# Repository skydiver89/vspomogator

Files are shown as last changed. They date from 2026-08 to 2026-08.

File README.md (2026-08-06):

**Languages**  
* [English](README.md)
* [Русский](README-RU.md)
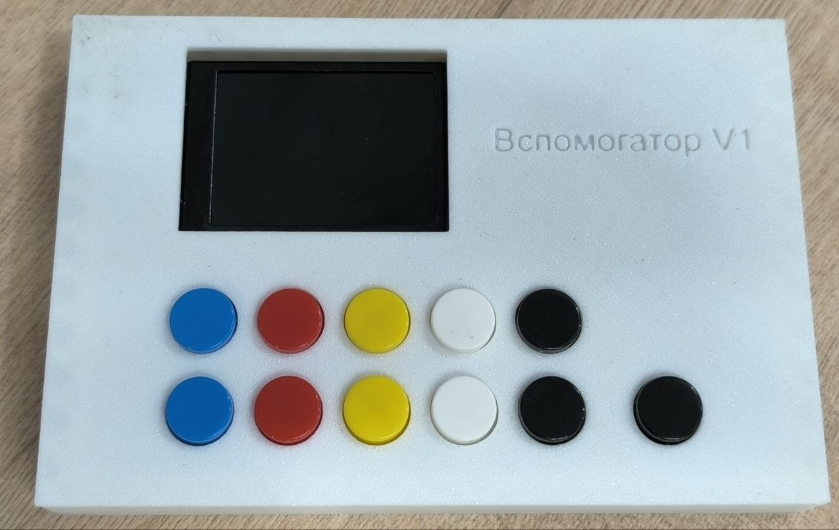
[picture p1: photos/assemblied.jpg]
Vspomogator V1

## Description  
**Vspomogator** — this is programmable macrokeyboard with display, which connecting to PC by USB (via virtual COM-port). Device allows to run commands, emulate text typing or pressing key combinations. Buttons grouped in layouts. Display shows current layout or sytsem info (CPU temperature and load, RAM usage, network activity, battery status). 11 buttons totally. Buttons are enumerated from 1 to 11 from left to right, from top to bottom.  
## Possibilities
- **2 modes**:
  - **Layouts mode**: shows button names according to configuration file.  
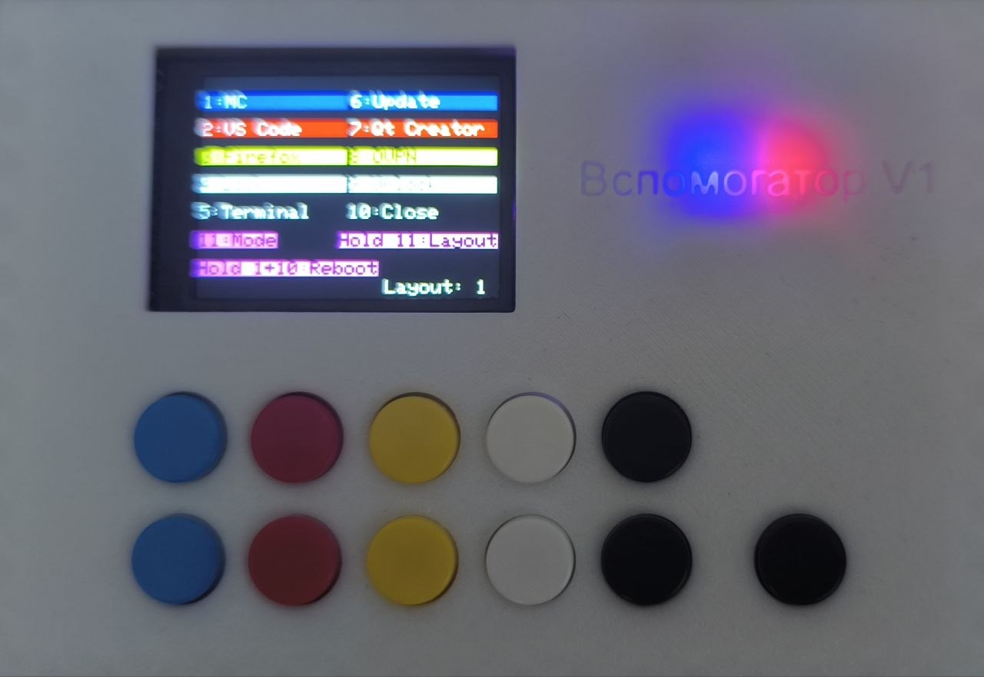
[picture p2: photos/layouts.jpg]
Layouts
  
  - **System info mode**: shows CPU load (common and by cores), RAM usage, CPU temperature, network activity (Tx/Rx) and battery status.  
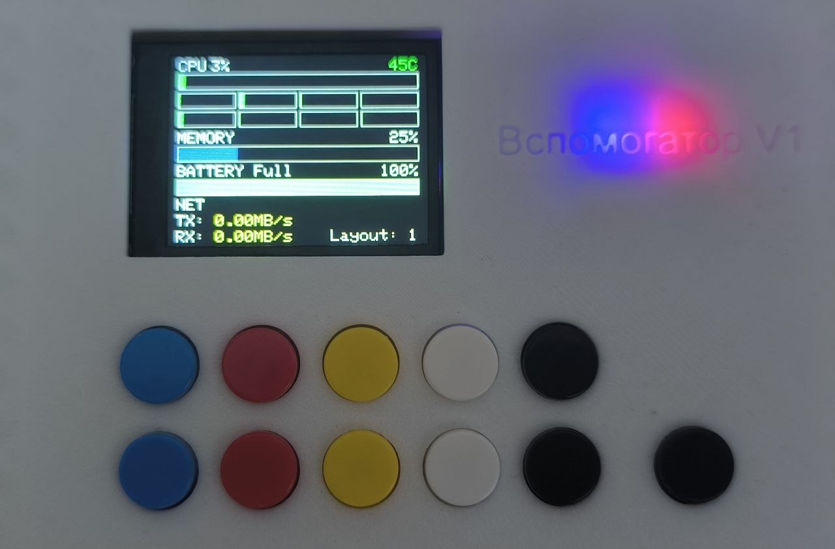
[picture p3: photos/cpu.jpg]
System info
  
- **Mode changing** is performing by pressing button 11.  
- **Layout changing** is performing by long pressing button 11.  
- **Reboot** is performing by long pressing buttons 1+10.  
## Materials used  
- **ESP32** DevKitV1 with CP2102 chip - some China clone. https://ozon.ru/t/zLtqDSa
- **TFT LCD display 240x320** on ST7789 chip. https://ozon.ru/t/WcsNvLD
- **11 tactile buttons** https://ozon.ru/t/3Qol6bx
- **breadboard** 12x8 https://ozon.ru/t/QWNoiOu
- **wires**
- **pin headers**. The display comes with a pin header for only one side. https://ozon.ru/t/dwWQEG1
- **device housing** is 3d-printed. Models are in *3d models* directory  
## Pinout  
### Display  
| ESP32 | ST7789 |
|---|---|
| 3V3 | VDD,BL |
| GND | GND |
| D2 | DC |
| D4 | RES |
| D5 | CS |
| D18 | SCL |
| D23 | SDA |
### Buttons  
One pin of each button is connected to the ESP32 GND. The second pins:
| ESP32 | Button |
|---|---|
| D13 | 1 |
| D14 | 2 |
| D16(RX2)| 3 |
| D17(TX2)| 4 |
| D19 | 5 |
| D21 | 6 |
| D22 | 7 |
| D25 | 8 |
| D26 | 9 |
| D27 | 10 |
| D33 | 11 |
## Element placing  
If you want to print the same housing, you need to place elements on breadboard exactly like in the photo:  
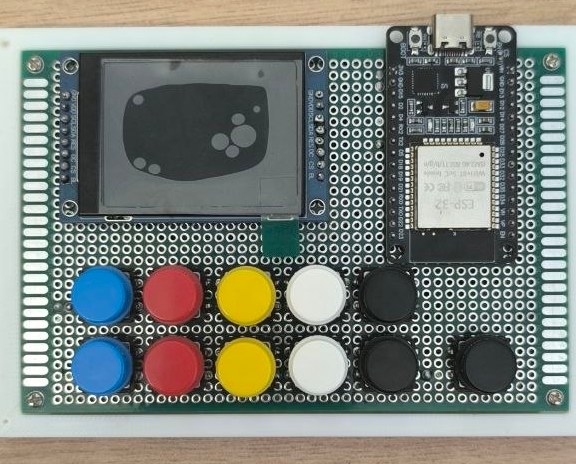
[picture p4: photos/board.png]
board
  
## Software  
### ESP32 firmware  
- In Arduino IDE choose board **ESP32 Dev Module**.
- Install libraries **TFT_eSPI**, **EncButton**, **ArduinoJson**.
- In library **TFT_eSPI** in file *UserSetup.h* (in my linux it`s location is *~/Arduino/libraries/TFT_eSPI/User_Setup.h*) change defines, as in file *User_Setup.h* in this repository. Or just replace the file.
- flash the ESP32.
### Service  
#### Requirements  
Out of the box it will work only in linux. For Windows it is should be modificated.  
#### Installation  
There is builded binary in relises for linux x86_64 and deb-package.  
There is also a systemd unit-file *service/buildscripts/vspomogator.service*. When the deb-package is installed, the systemd service will be installed and activated automatically, and the configuration file will be located at */etc/vspomogator/vspomogator.yml*.  
#### Building from source  
The Go compiler must be installed. Run the following in the directory *service*:

```
make
```

To build a deb package, [fpm](https://github.com/jordansissel/fpm) must be installed. Run the following in the directory *service*:

```
make deb
```

Binary and deb-package will appear in *build* directory.  
#### CLI arguments  

```
Usage: vspomogator [-c config] [-h] [-v]
  -c string
    	Path to config (default "vspomogator.yml")
  -h	Show this help
  -v	Show version
```

#### Configuration file  

```
port: /dev/ttyUSB0                     # The port to which the ESP32 is connected. It can be found in /dev/. It is usually /dev/ttyUSB0
layouts:
  - buttons:                           # first layout
    - label: MC                        # label on display
      type: command                    # action type (command - command, keytype - emulate keyaboard typing, keyseq - key combination. command is default)
      command:
        com: terminator                # Command to launch
        args: [-e, mc]                 # Arguments of command
    - label: Close
      type: keyseq                     # key combination
      command:
        com: "f4"                      # main key
        args: ["alt"]                  # modificators
    - label: Hello
      type: keytype                    # keyboard typing
      command:
        com: Hello, world!             # text to type
        hitenter: true                 # press enter after typing
  - buttons:                           # second layout
    ...
```

Modificators and keys for combinations look [here](https://github.com/go-vgo/robotgo/blob/master/docs/keys.md)

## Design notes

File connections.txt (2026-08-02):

ESP32	|	ST7789
----------------------
3V3	|	VDD,BL
GND	|	GND
D2	|	DC
D4	|	RES
D5	|	CS
D18	|	SCL
D23	|	SDA

1 pin of every button to GND, another one to:
ESP32	|	Buttons
-----------------------
D13	|	1
D14	|	2
D16(RX2)|	3
D17(TX2)|	4
D19	|	5
D21	|	6
D22	|	7
D25	|	8
D26	|	9
D27	|	10
D33	|	11

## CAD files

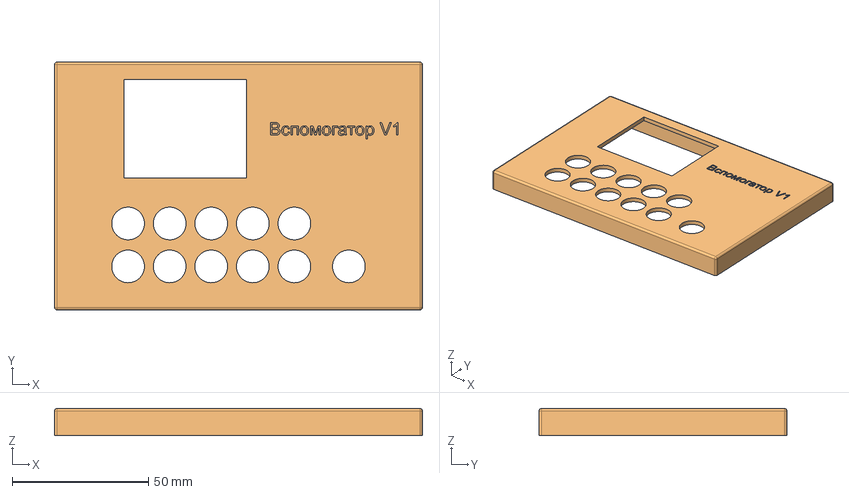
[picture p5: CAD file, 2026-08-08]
3d models/espboard_top.FCStd
135.0 x 91.0 x 10.0 mm
ShapeString

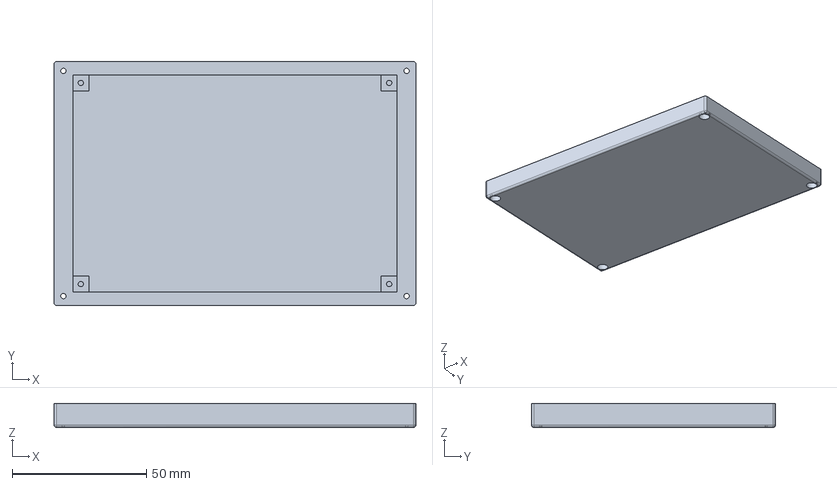
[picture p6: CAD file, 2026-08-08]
3d models/espboard_bottom.FCStd
135.0 x 91.0 x 9.00 mm

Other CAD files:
3d models/espboard_bottom.stl
3d models/espboard_top.stl

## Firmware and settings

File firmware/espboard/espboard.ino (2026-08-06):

#include <TFT_eSPI.h>
#include <SPI.h>
#include <EncButton.h>
#include <ArduinoJson.h>

#define INITREQ "begincmdinitendcmd"
#define INITOK "begincmdinitokendcmd"
#define STATREQ "begincmdstatendcmd"
#define INITINTERVAL 1000
#define STATINTERVAL 1000
#define RX_LINE_MAX 2048

bool initialized = false;
unsigned long lastInitSent = 0;
unsigned long lastStatSent = 0;
bool STATMODE = false;
bool statDrawn = false;
int curLayout = 0;
int layoutNum = 0;
JsonDocument conf;
String rxLine;

const int numBtns = 11;
Button btns[] = {Button(13), Button(14), Button(16), Button(17), Button(19),
                 Button(21), Button(22), Button(25), Button(26), Button(27), Button(33)};
VirtButton resetButton;

TFT_eSPI tft = TFT_eSPI();

void setup() {
  Serial.begin(115200);
  delay(100);
  tft.init();
  tft.setRotation(3);
  tft.fillScreen(TFT_BLACK);
  tft.setTextColor(TFT_WHITE, TFT_BLACK);
  tft.setTextSize(3);
  tft.drawString("Initializing...", 25, 110);
  tft.setTextSize(2);
  rxLine.reserve(256);
}

// Non-blocking: never deserializeJson(Serial) — it blocks loop()/buttons.
bool pollSerialLine(String &line) {
  while (Serial.available() > 0) {
    char c = (char)Serial.read();
    if (c == '\n' || c == '\r') {
      if (rxLine.length() == 0)
        continue;
      line = rxLine;
      rxLine = "";
      return true;
    }
    rxLine += c;
    if (rxLine.length() > RX_LINE_MAX)
      rxLine = "";
  }
  return false;
}

void drawLayout() {
  JsonArray root = conf.as<JsonArray>();
  JsonObject layout = root[curLayout].as<JsonObject>();
  JsonArray buttons = layout["Buttons"].as<JsonArray>();
  int x = 0;
  int y = 20;
  for (int i = 0; i < 10; i++) {
    String label = "";
    if (i < buttons.size()) {
      JsonObject btn = buttons[i].as<JsonObject>();
      label = String(btn["Label"]);
    }

    while (label.length() < 11)
      label += " ";
    if (i >= 5)
      x = 160;
    if (i == 0 || i == 5)
      tft.setTextColor(TFT_WHITE, TFT_BLUE);
    if (i == 1 || i == 6)
      tft.setTextColor(TFT_WHITE, TFT_RED);
    if (i == 2 || i == 7)
      tft.setTextColor(TFT_BLACK, TFT_YELLOW);
    if (i == 3 || i == 8)
      tft.setTextColor(TFT_BLACK, TFT_WHITE);
    if (i == 4 || i == 9)
      tft.setTextColor(TFT_WHITE, TFT_BLACK);
    tft.drawString(String(i + 1) + ":" + label, x, y);
    y += 30;
    if (i == 4)
      y = 20;
  }
  tft.setTextColor(TFT_BLACK, TFT_MAGENTA);
  tft.drawString("11:Mode", 0, 170);
  tft.drawString("Hold 11:Layout", 150, 170);
  tft.drawString("Hold 1+10:Reboot", 0, 200);
  tft.setTextColor(TFT_WHITE, TFT_BLACK);
  tft.drawString("Layout: " + String(curLayout + 1), 200, 220);
}

void requestInit() {
  unsigned long now = millis();
  if (now - lastInitSent < INITINTERVAL)
    return;
  lastInitSent = now;
  Serial.print(INITREQ);
}

void requestStat() {
  unsigned long now = millis();
  if (now - lastStatSent < STATINTERVAL)
    return;
  lastStatSent = now;
  Serial.print(STATREQ);
}

void handleConfig(JsonVariant data) {
  if (!data.is<JsonArray>())
    return;
  JsonArray root = data.as<JsonArray>();
  if (root.size() == 0)
    return;

  conf.clear();
  conf.set(data);
  layoutNum = root.size();
  if (curLayout >= layoutNum)
    curLayout = 0;

  bool wasInit = initialized;
  initialized = true;
  tft.fillScreen(TFT_BLACK);
  tft.setTextSize(2);
  drawLayout();
  if (!wasInit)
    Serial.print(INITOK);
}

void drawBar(int x, int y, int width, int height, int percentage, uint16_t color) {
  if (percentage < 0) percentage = 0;
  if (percentage > 100) percentage = 100;
  
  if(!statDrawn)
    tft.drawRect(x, y, width, height, TFT_WHITE);

  if (percentage > 0) {
    int fillWidth = (width - 2) * percentage / 100;
    tft.fillRect(x + 1, y + 1, fillWidth, height - 2, color);
    tft.fillRect(x + 1 + fillWidth, y + 1, width - 2 - fillWidth, height - 2, TFT_BLACK);
  }
}

uint16_t getLoadColor(int percentage) {
  if (percentage < 50) return TFT_GREEN;
  if (percentage < 75) return TFT_YELLOW;
  return TFT_RED;
}

void drawStatBar(int x, int y, int width, int height, const char* label, int percentage, uint16_t color, int textSize) {
  tft.setTextColor(TFT_WHITE, TFT_BLACK);
  tft.setTextSize(textSize);
  tft.drawString(label, x, y);
  
  String value = String(percentage) + "%";
  int valueX = x + width - tft.textWidth(value);
  tft.setTextColor(TFT_WHITE, TFT_BLACK);
  tft.drawString(value, valueX, y);
  
  drawBar(x, y + textSize * 8 + 2, width, height, percentage, color);
}

void handleStat(JsonVariant data) {
  if (!data.is<JsonObject>()) {
    return;
  }
  
  JsonObject stat = data.as<JsonObject>();
  
  int cores = stat["cores"];
  JsonArray percs = stat["percs"].as<JsonArray>();
  int mem = stat["mem"];
  int cputemp = stat["cputemp"];
  
  const char* nettx = stat["nettx"];
  const char* netrx = stat["netrx"];
  int bat = stat["bat"] | 0;
  const char* batstat = stat["batstat"];

  int totalLoad = 0;
  int coreCount = percs.size();
  
  int startY = 5;
  int barHeight = 20;
  int barStartX = 10;
  int barWidth = 300;
  
  int totalPerc = 0;
  for (int i = 0; i < coreCount; i++) {
    totalPerc += percs[i] | 0;
  }
  int avgLoad = coreCount > 0 ? totalPerc / coreCount : 0;
  
  tft.setTextSize(2);
  tft.setTextColor(TFT_WHITE, TFT_BLACK);
  tft.drawString("CPU", barStartX, startY);
  
  String cpuStr = String(avgLoad) + "%  ";
  int cpuX = barStartX + tft.textWidth("CPU") + 5;
  tft.drawString(cpuStr, cpuX, startY);
  
  String tempStr = String(cputemp) + "C";
  uint16_t tempColor = TFT_GREEN;
  if (cputemp > 75) tempColor = TFT_RED;
  else if (cputemp > 60) tempColor = TFT_YELLOW;
  tft.setTextColor(tempColor, TFT_BLACK);
  int tempX = barStartX + barWidth - tft.textWidth(tempStr);
  tft.drawString(tempStr, tempX, startY);
  
  drawBar(barStartX, startY + 18, barWidth, barHeight, avgLoad, getLoadColor(avgLoad));
  startY += barHeight + 22;
  
  int coresPerRow = (coreCount + 1) / 2;
  int barH = barHeight;
  
  int coreBarWidth = (barWidth - (coresPerRow - 1) * 4) / coresPerRow;
  if (coreBarWidth < 20) coreBarWidth = 20;
  
  int rowSpacing = 4;
  
  for (int row = 0; row < 2; row++) {
    int rowStart = row * coresPerRow;
    int rowEnd = min(rowStart + coresPerRow, coreCount);
    int rowCols = rowEnd - rowStart;
    
    if (rowCols == 0) break;
    
    int rowWidth = rowCols * (coreBarWidth + 4) - 4;
    int rowStartX = barStartX + (barWidth - rowWidth) / 2;
    int y = startY + row * (barH + rowSpacing);
    
    for (int i = rowStart; i < rowEnd; i++) {
      int perc = percs[i] | 0;
      int x = rowStartX + (i - rowStart) * (coreBarWidth + 4);
      
      drawBar(x, y, coreBarWidth, barH, perc, getLoadColor(perc));
    }
  }
  
  startY += 2 * (barH + rowSpacing) + 2;
  
  drawStatBar(barStartX, startY, barWidth, barHeight, "MEMORY", mem, TFT_BLUE, 2);
  startY += barHeight + 22;
  
  uint16_t batColor = TFT_GREEN;
  if (bat < 20) batColor = TFT_RED;
  else if (bat < 50) batColor = TFT_YELLOW;
  
  String batStatusText = String(batstat);
  while(batStatusText.length() < 11)
    batStatusText+=" ";
  
  tft.setTextColor(TFT_WHITE, TFT_BLACK);
  tft.setTextSize(2);
  tft.drawString("BATTERY " + batStatusText, barStartX, startY);
  
  String value =String(bat) + "%";
  while(value.length() < 4)
    value = " " + value;
  int valueX = barStartX + barWidth - tft.textWidth(value);
  tft.setTextColor(TFT_WHITE, TFT_BLACK);
  tft.drawString(value, valueX, startY);
  
  drawBar(barStartX, startY + 18, barWidth, barHeight, bat, batColor);
  startY += barHeight + 22;
  
  tft.setTextSize(2);
  tft.drawString("NET", barStartX, startY);
  startY += 20;
  tft.setTextColor(TFT_WHITE, TFT_BLACK);
  tft.drawString("TX: ", barStartX, startY);
  tft.setTextColor(TFT_YELLOW, TFT_BLACK);
  tft.drawString(String(nettx) + "     ", barStartX + tft.textWidth("TX: "), startY);
  startY += 20;
  tft.setTextColor(TFT_WHITE, TFT_BLACK);
  tft.drawString("RX: ", barStartX, startY);
  tft.setTextColor(TFT_YELLOW, TFT_BLACK);
  tft.drawString(String(netrx) + "     ", barStartX + tft.textWidth("RX: "), startY);
  tft.setTextColor(TFT_WHITE, TFT_BLACK);
  
  tft.setTextSize(2);
  tft.setTextColor(TFT_WHITE, TFT_BLACK);
  tft.drawString("Layout: " + String(curLayout + 1), 200, 220);
  statDrawn = true;
}

void handleHostMessage(const String &line) {
  JsonDocument doc;
  DeserializationError error = deserializeJson(doc, line);
  if (error) {
    return;
  }

  const char *type = doc["type"];
  if (!type)
    return;

  if (strcmp(type, "config") == 0) {
    handleConfig(doc["data"]);
    return;
  }

  if (strcmp(type, "stat") == 0) {
    handleStat(doc["data"]);
    return;
  }
}

void pollHost() {
  String line;
  while (pollSerialLine(line))
    handleHostMessage(line);
}

void loop() {
  for (int i = 0; i < numBtns; i++)
    btns[i].tick();
  resetButton.tick(btns[0], btns[9]);

  if (resetButton.hold()) {
    tft.fillScreen(TFT_BLACK);
    tft.setTextSize(3);
    tft.drawString("Rebooting...", 40, 110);
    ESP.restart();
  }

  pollHost();

  if (!initialized) {
    requestInit();
    return;
  }

  if (STATMODE)
    requestStat();

  for (int i = 0; i < numBtns; i++) {
    if (btns[i].click() && i != 10)
      Serial.print("begincmdbutton " + String(curLayout + 1) + "-" + String(i + 1) + "endcmd");
  }
  if (btns[10].click()){
    tft.fillScreen(TFT_BLACK);
    STATMODE = !STATMODE;
    statDrawn = false;
    if(!STATMODE)
      drawLayout();
  }
  if (btns[10].hold()) {
    curLayout++;
    if (curLayout >= layoutNum)
      curLayout = 0;
    tft.drawString("Layout: " + String(curLayout + 1), 200, 220);
    if(!STATMODE)
      drawLayout();
  }
}

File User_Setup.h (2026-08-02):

//                            USER DEFINED SETTINGS
//   Set driver type, fonts to be loaded, pins used and SPI control method etc.
//
//   See the User_Setup_Select.h file if you wish to be able to define multiple
//   setups and then easily select which setup file is used by the compiler.
//
//   If this file is edited correctly then all the library example sketches should
//   run without the need to make any more changes for a particular hardware setup!
//   Note that some sketches are designed for a particular TFT pixel width/height

// User defined information reported by "Read_User_Setup" test & diagnostics example
#define USER_SETUP_INFO "User_Setup"
#define TFT_RGB_ORDER TFT_BGR

// Define to disable all #warnings in library (can be put in User_Setup_Select.h)
//#define DISABLE_ALL_LIBRARY_WARNINGS

// ##################################################################################
//
// Section 1. Call up the right driver file and any options for it
//
// ##################################################################################

// Define STM32 to invoke optimised processor support (only for STM32)
//#define STM32

// Defining the STM32 board allows the library to optimise the performance
// for UNO compatible "MCUfriend" style shields
//#define NUCLEO_64_TFT
//#define NUCLEO_144_TFT

// STM32 8-bit parallel only:
// If STN32 Port A or B pins 0-7 are used for 8-bit parallel data bus bits 0-7
// then this will improve rendering performance by a factor of ~8x
//#define STM_PORTA_DATA_BUS
//#define STM_PORTB_DATA_BUS

// Tell the library to use parallel mode (otherwise SPI is assumed)
//#define TFT_PARALLEL_8_BIT
//#defined TFT_PARALLEL_16_BIT // **** 16-bit parallel ONLY for RP2040 processor ****

// Display type -  only define if RPi display
//#define RPI_DISPLAY_TYPE // 20MHz maximum SPI

// Only define one driver, the other ones must be commented out
//#define ILI9341_DRIVER       // Generic driver for common displays
//#define ILI9341_2_DRIVER     // Alternative ILI9341 driver, see https://github.com/Bodmer/TFT_eSPI/issues/1172
//#define ST7735_DRIVER      // Define additional parameters below for this display
//#define ILI9163_DRIVER     // Define additional parameters below for this display
//#define S6D02A1_DRIVER
//#define RPI_ILI9486_DRIVER // 20MHz maximum SPI
//#define HX8357D_DRIVER
//#define ILI9481_DRIVER
//#define ILI9486_DRIVER
//#define ILI9488_DRIVER     // WARNING: Do not connect ILI9488 display SDO to MISO if other devices share the SPI bus (TFT SDO does NOT tristate when CS is high)
#define ST7789_DRIVER      // Full configuration option, define additional parameters below for this display
//#define ST7789_2_DRIVER    // Minimal configuration option, define additional parameters below for this display
//#define R61581_DRIVER
//#define RM68140_DRIVER
//#define ST7796_DRIVER
//#define SSD1351_DRIVER
//#define SSD1963_480_DRIVER
//#define SSD1963_800_DRIVER
//#define SSD1963_800ALT_DRIVER
//#define ILI9225_DRIVER
//#define GC9A01_DRIVER

// Some displays support SPI reads via the MISO pin, other displays have a single
// bi-directional SDA pin and the library will try to read this via the MOSI line.
// To use the SDA line for reading data from the TFT uncomment the following line:

// #define TFT_SDA_READ      // This option is for ESP32 ONLY, tested with ST7789 and GC9A01 display only

// For ST7735, ST7789 and ILI9341 ONLY, define the colour order IF the blue and red are swapped on your display
// Try ONE option at a time to find the correct colour order for your display

//  #define TFT_RGB_ORDER TFT_RGB  // Colour order Red-Green-Blue
//  #define TFT_RGB_ORDER TFT_BGR  // Colour order Blue-Green-Red

// For M5Stack ESP32 module with integrated ILI9341 display ONLY, remove // in line below

// #define M5STACK

// For ST7789, ST7735, ILI9163 and GC9A01 ONLY, define the pixel width and height in portrait orientation
// #define TFT_WIDTH  80
// #define TFT_WIDTH  128
// #define TFT_WIDTH  172 // ST7789 172 x 320
// #define TFT_WIDTH  170 // ST7789 170 x 320
 #define TFT_WIDTH  240 // ST7789 240 x 240 and 240 x 320
// #define TFT_HEIGHT 160
// #define TFT_HEIGHT 128
// #define TFT_HEIGHT 240 // ST7789 240 x 240
 #define TFT_HEIGHT 320 // ST7789 240 x 320
// #define TFT_HEIGHT 240 // GC9A01 240 x 240

// For ST7735 ONLY, define the type of display, originally this was based on the
// colour of the tab on the screen protector film but this is not always true, so try
// out the different options below if the screen does not display graphics correctly,
// e.g. colours wrong, mirror images, or stray pixels at the edges.
// Comment out ALL BUT ONE of these options for a ST7735 display driver, save this
// this User_Setup file, then rebuild and upload the sketch to the board again:

// #define ST7735_INITB
// #define ST7735_GREENTAB
// #define ST7735_GREENTAB2
// #define ST7735_GREENTAB3
// #define ST7735_GREENTAB128    // For 128 x 128 display
// #define ST7735_GREENTAB160x80 // For 160 x 80 display (BGR, inverted, 26 offset)
// #define ST7735_ROBOTLCD       // For some RobotLCD Arduino shields (128x160, BGR, https://docs.arduino.cc/retired/getting-started-guides/TFT)
// #define ST7735_REDTAB
// #define ST7735_BLACKTAB
// #define ST7735_REDTAB160x80   // For 160 x 80 display with 24 pixel offset

// If colours are inverted (white shows as black) then uncomment one of the next
// 2 lines try both options, one of the options should correct the inversion.

// #define TFT_INVERSION_ON
// #define TFT_INVERSION_OFF


// ##################################################################################
//
// Section 2. Define the pins that are used to interface with the display here
//
// ##################################################################################

// If a backlight control signal is available then define the TFT_BL pin in Section 2
// below. The backlight will be turned ON when tft.begin() is called, but the library
// needs to know if the LEDs are ON with the pin HIGH or LOW. If the LEDs are to be
// driven with a PWM signal or turned OFF/ON then this must be handled by the user
// sketch. e.g. with digitalWrite(TFT_BL, LOW);

// #define TFT_BL   32            // LED back-light control pin
// #define TFT_BACKLIGHT_ON HIGH  // Level to turn ON back-light (HIGH or LOW)
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

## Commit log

2026-08-02 3d models
    [espboard_bottom.FCStd, espboard_bottom.stl, espboard_top.FCStd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]
2026-08-02 settings for tft_eSPI arduino lib
2026-08-02 photos of device
2026-08-08 3d models improved
    [espboard_bottom.FCStd, espboard_bottom.stl, espboard_top.FCStd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]
2026-08-19 Disable error output about battery
